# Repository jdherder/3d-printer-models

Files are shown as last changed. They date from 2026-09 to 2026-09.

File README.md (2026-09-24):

# 3D Printer Models

Models for 3D printing on a **Bambu Lab A1**: scans from Polycam (iOS), edits in
Autodesk Fusion, and reproducible Python cleanup pipelines.

## Projects

| Project | Status | Description |
|---|---|---|
| [gate-footing](projects/gate-footing/) | Real size (100 mm), print-ready STEP + STL; next: test print | Plastic foot that holds up a metal gate |

## Layout

- `projects/<name>/` has one folder per model: `source/` (raw), `build.py`,
  `output/` (print-ready), `renders/` (previews), and a `README.md` with status and notes
- `tools/` holds shared mesh tooling (`meshkit.py`, `render.py`, `inspect_mesh.py`)
- `docs/` holds workflow notes for the [A1](docs/bambu-a1.md), [Fusion](docs/fusion.md),
  [Polycam scanning](docs/scanning-polycam.md), and the [model review process](docs/review.md)
- `CLAUDE.md` is guidance for AI agents working in this repo

## Quick start

```bash
pip install -r requirements.txt
python projects/gate-footing/build.py
python tools/inspect_mesh.py projects/gate-footing/output/gate-footing.stl
python tools/make_viewer.py projects/gate-footing   # interactive 3D review page
```

New project: copy `projects/_template/` to `projects/<name>/` and fill in the README.

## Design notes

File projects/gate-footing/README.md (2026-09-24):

# Gate footing

A plastic foot that holds up a metal gate. It's a rectangular base slab with
two raised uprights running front to back, and a slot between them where the gate sits.

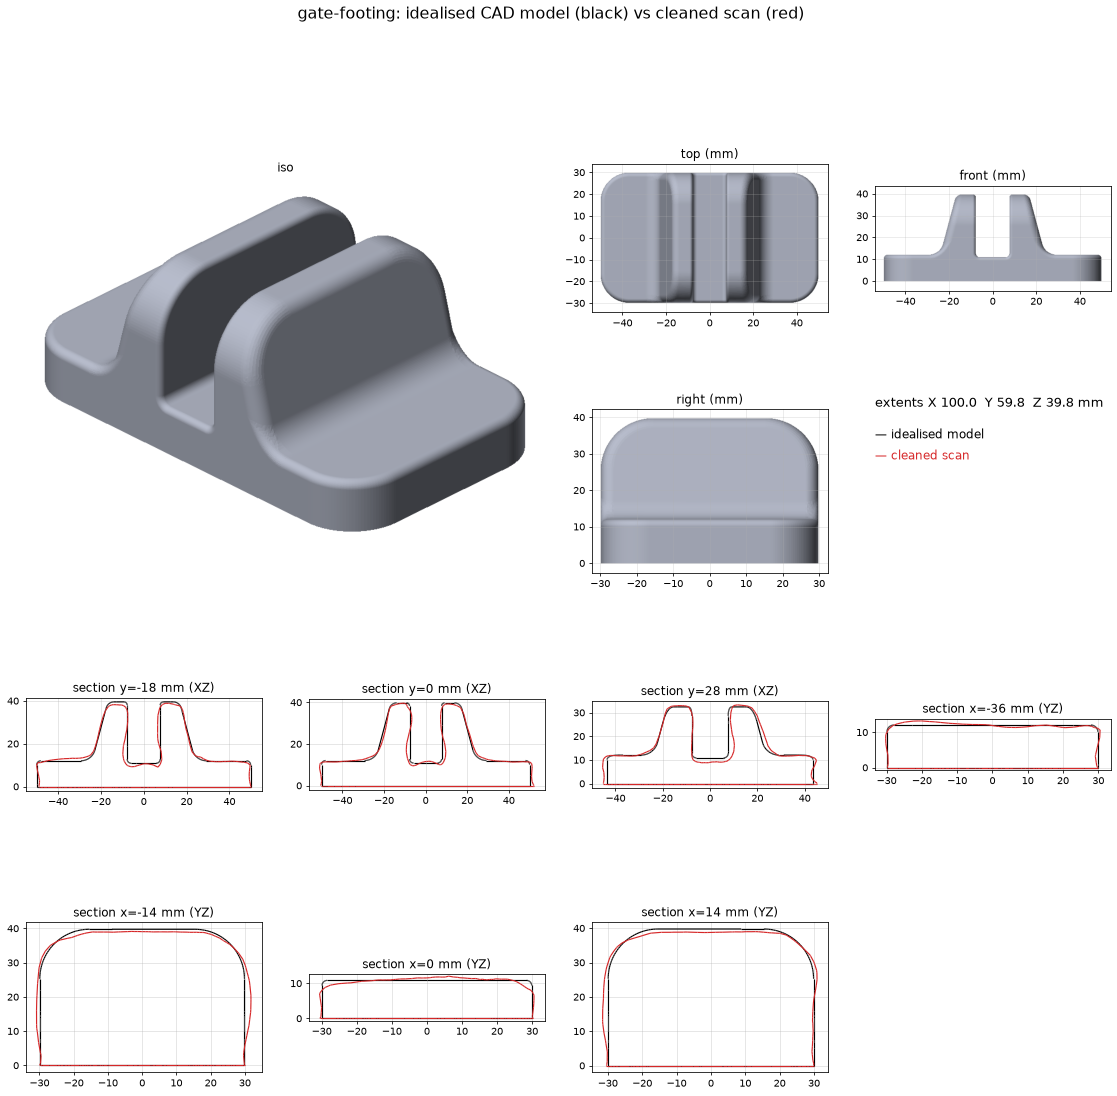
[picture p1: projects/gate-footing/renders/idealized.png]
idealised model vs scan


## Goal

A clean, smooth, accurate, printable model of the footing. The real part has smooth
sides and edges, and the scan is wavy, so the deliverable is an **idealised
parametric CAD model** fitted to the scan, not a smoothed scan.
*(Owner to confirm the end use: print a replacement? exact replica or improved?)*

## Status

- [x] Polycam scan imported (`source/polycam-2026-09-24.glb`)
- [x] Scan cleaned: floor removed, levelled, squared up, flat base, watertight
- [x] **Idealised CAD model** (`idealized.py`, build123d): flat faces, flat parallel
      slot walls, straight drafts, true fillets, mirror-symmetric. Exported as
      STEP (Fusion) and STL (Bambu Studio). Mean deviation from the scan is 0.6 mm at real size
      (2.5 mm at scan scale), mostly where the scan is wavy.
- [x] **Real size:** 100 mm long (the owner's measurement) with the slot modelled at 15.4 mm (caliper 15.1 mm + print clearance). Output is 100 × 59.8 × 39.8 mm and
      fits the A1 in one piece.
- [ ] Check the width (59.8), height (39.8) and base thickness (12.0) against the real part.
      These are scaled from the scan, not measured.
- [ ] Underside: solid, hollow, or ribbed? (not captured)
- [ ] Choose the material and orientation, then test print (scale down first to check the fit?)

## Measurements

**Real (owner, 2026-09-24):** longest dimension **100 mm**. Slot **15.1 mm** (caliper). The first estimate was "right around 15".
Both are set in `build.py` (`MEASURED_LENGTH_X_MM`, `MEASURED_OVERRIDES`). The two agree:
scaling the scan to 100 mm makes the slot 15.9 mm, which confirms the scan's proportions.

`FootingParams` in `idealized.py` holds the values at scan scale. Real = scan × k, where k = 100 / 415 = 0.241.
Only **measured** values were measured directly. Everything else is scaled from the scan.

| Parameter | Scan scale (mm) | Real (mm) | Source |
|---|---|---|---|
| `length`: end wall to end wall (X) | 415 | **100.0** | measured |
| `width`: along the slot (Y) | 248 | 59.8 | scaled |
| `height`: top of the uprights | 165 | 39.8 | scaled |
| `base_h`: base slab thickness | 50 | 12.0 | scaled |
| `slot_w`: gap between the uprights | 66 | **15.4** | measured 15.1 + 0.3 print clearance |
| `slot_floor`: slot floor height | 45 | 10.8 | scaled |
| `upright_outer_x`: outer face at base top, from centre | 100 | 24.1 | scaled |
| `upright_draft_deg`: outer face lean | 15° | 15° | scan |
| `footprint_corner_r` | 55 | 13.3 | scaled |
| `upright_fillet_r` (upright to base) | 28 | 6.7 | scaled |
| `upright_end_r` (top corners at the Y ends) | 60 | 14.5 | scaled |
| `upright_top_outer_r` / `upright_top_inner_r` | 15 / 6 | 3.6 / 1.4 | scaled |
| `base_edge_r` / `slot_floor_r` | 8 / 8 | 1.9 / 1.9 | scaled |

## Modelling decisions (idealised model)

- **The slot walls are flat, parallel, and vertical** (as the owner described). The scan's
  slot interior is its noisiest area (the camera can't see into it), and it read as 60–75 mm
  wide at scan scale depending on height. The model uses the owner's caliper reading of 15.1 mm plus
  0.3 mm clearance, so **15.4 mm**.
- The upright *outer* faces have a 15° draft. That's consistent across the scan
  (x = 92 → 76 mm over z = 80 → 140).
- The part is mirror-symmetric about the slot centre. The scan's slot centre was 2.5 mm off,
  and the cleaned scan is shifted to match.
- The upright top edges are flat and rounded. The scan's top is slightly crowned (≤3 mm),
  which is treated as noise.
- Solid underneath. The real underside is unknown. For printing, use infill or
  hollow it later.

## Printing notes

- 100 × 59.8 × 39.8 mm, so it easily fits the A1 in one piece. Print it **base down with no supports**:
  the drafts, fillets and rounded upright ends are all self-supporting.
- Solid volume is 110 cm³. With 4–5 walls and 20–30 % gyroid infill, expect roughly 50–70 g.
- Outdoors under load: **PETG**.
- The slot is modelled at 15.4 mm so that it prints at about the real 15.1 mm (printed slots usually come out
  ~0.2–0.3 mm narrow). If the test print is too tight or too loose, adjust `slot_w` in `MEASURED_OVERRIDES`
  and rebuild.

## Pipeline

`python projects/gate-footing/build.py` (about 1.5 min):
1. **Scan cleanup** (`tools/meshkit.py`): merge seam vertices → RANSAC ground plane,
   level to Z=0 (mm, Z-up) → keep the largest piece above 2 mm → crop to a 400 mm radius →
   square the footprint → drop the cut edge to Z=0 and cap → watertight.
2. **Idealised model** (`idealized.py`, build123d/OpenCASCADE): base box → drafted
   upright block → slot cut → fillets. The model is **always built at scan scale**, with
   measured overrides converted to that scale, and then the finished solid is scaled by k.
   At 100 mm the small fillets tessellated into self-intersections, and a uniform scale of the
   finished solid is exact. Exported as STEP. Tessellated and repaired to STL
   (`meshkit.cad_to_mesh`).
3. Scale the scan by the same k, write `report.json` (checks and scan-to-model
   deviation), and render the PNGs.

## Files

- **Interactive viewer:** https://claude.ai/artifact/99u6vaQgsGqaAUmchUXR9R
  (private to the owner). Built from `renders/viewer.html` by `tools/make_viewer.py` using
  `review.json`. Republish to this URL on every review (see `docs/review.md`).
- `source/polycam-2026-09-24.glb`: raw Polycam export (≈2 m of ground around the part)
- `output/gate-footing.step`: **idealised model for Fusion** (editable solid)
- `output/gate-footing.stl`: idealised model for Bambu Studio
- `output/gate-footing-scan-clean.stl`: cleaned but wavy scan, useful as a reference body in Fusion
- `output/report.json`: dimensions, watertight/self-intersection checks, deviation, params
- `renders/idealized.png`: model vs scan, views and cross-sections
- `renders/scan-clean.png`, `renders/raw-scan-context.png`

## Log

- **2026-09-24:** Repo set up. Scan cleaned into a watertight solid. The owner flagged that the size
  is wrong: the scan has no floor left, so the photo-mode scan scale is at fault. Waiting on
  measurements. The owner asked for smooth sides and flat faces, so I built the idealised
  parametric CAD model (build123d), which is symmetric with flat slot walls and real fillets, exported
  as STEP and STL. Watertight, 0 self-intersections.
- **2026-09-24:** First review with the interactive 3D viewer (link above). The owner was happy with
  the idealised shape. The review process is now documented (`docs/review.md`, `/model-review`).
  Next: real measurements for scale.
- **2026-09-24:** Owner measured a 100 mm length and a ~15 mm slot. These agree with the scan's
  proportions (15.9 mm predicted). I rebuilt at real size: 100 × 59.8 × 39.8 mm, watertight, 0
  self-intersections, 0.6 mm mean deviation from the scan, fits the A1. Fixed two scale problems: the base-edge
  selection threshold is now relative to the model's size, and the CAD is built at reference scale and then
  scaled (building directly at 100 mm gave 54 self-intersecting triangles). The viewer now frames the
  part rather than the whole build volume. Next: the owner checks the remaining dimensions, then a test print.
- **2026-09-24:** Owner's caliper reads the slot at ~15.1 mm, and they asked to widen it. Set `slot_w` to 15.4
  (15.1 + 0.3 mm print clearance). Rebuilt: watertight, 0 self-intersections, slot 15.4 mm at every height.
  Next: test print and check the gate fit.

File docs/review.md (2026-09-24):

# Model review process

Use this to review a model with the owner after any meaningful change (first
cleanup, idealised rebuild, new measurements, a fix after a test print). It
pairs the agent's automated checks with an **interactive 3D page** the owner
can spin around on any device.

In a Claude session, run **`/model-review <project>`** (skill:
`.claude/skills/model-review/`). It runs every step below.

## 1. Rebuild from source

```bash
python projects/<name>/build.py
```

Outputs are always regenerated, never hand-edited. The build must finish
without assertion failures.

## 2. Automated checks (agent)

Read `projects/<name>/output/report.json` and confirm:

| Check | Pass |
|---|---|
| `watertight`, `winding_consistent` | `true` |
| `self_intersecting_faces` | `0` |
| `euler_number` | `2` for a single solid with no through-holes (each through-hole subtracts 2) |
| `scale_status` | Measured. If it's still scan scale, **say so plainly**, because the size is not real |
| `fits_A1_as_is` / `fits_A1_any_axis_order` | If false, the part needs splitting or scaling |
| `scan_to_model_deviation_mm` (idealised models) | Mean within a few mm. Look at *where* the large deviations are |

For any other mesh: `python tools/inspect_mesh.py <file>`.

## 3. Visual check (agent)

Read the PNGs in `projects/<name>/renders/` (the agent can't open a 3D viewer,
but it can look at images):
- Shaded views: does the shape look right, and are there artefacts (spikes, holes, a leftover floor)?
- Cross-sections, model (black) vs scan (red): the model should sit on the scan's
  average surface. A consistent offset in one place is a modelling error, not
  scan noise.

Fix anything found before involving the owner.

## 4. Interactive review page

```bash
python tools/make_viewer.py projects/<name>
```

This reads `projects/<name>/review.json` and writes `renders/viewer.html`, a
single self-contained page (~0.5–1 MB) with:
- orbit, zoom, and pan, plus Iso/Front/Side/Top buttons
- a toggle for each mesh (e.g. the idealised model as a solid, the original scan as a wireframe overlay)
- the Bambu A1 256 mm build volume for size context
- a **"preview at real size"** box: type a length and every dimension plus the A1
  fit check updates
- a notes panel (what changed, what to look at)

`review.json` fields are documented at the top of `tools/make_viewer.py`.
Dimensions can point at model parameters (`"param": "slot_w"`), so the page always
matches the last build. Meshes must be under 65k vertices.

**Share it:** in a Claude session, publish `renders/viewer.html` as an Artifact.
Record the artifact URL in the project README (under *Files*). Next time,
publish to that same URL so the owner's link keeps working. Without Claude, open
`viewer.html` in a browser (it needs internet access for three.js).

## 5. Owner review checklist

Ask the owner to look for:
1. **Shape:** does it match the real part? Anything missing, like holes, ribs, or text?
2. **Flat faces and edges:** are faces flat where they should be, and are the edge
   roundings about the right size?
3. **Scan overlay:** toggle the scan on. Where the model and scan disagree, which is right?
4. **Size:** type the measured length into the real-size box. Do the listed
   dimensions (slot width etc.) match their tape measure?
5. **Fit and printing:** does it fit the A1? Any orientation or material concerns?

## 6. Record the outcome

In the project README:
- tick or add items under **Status**
- put new real measurements in **Measurements**, and in `build.py`
  (`MEASURED_LENGTH_X_MM` / `MEASURED_OVERRIDES`)
- add a dated **Log** entry: what was reviewed, the owner's feedback, and what changes next

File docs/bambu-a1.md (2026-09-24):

# Bambu Lab A1 notes

- **Build volume:** 256 × 256 × 256 mm. Parts bigger than that get split, with
  alignment pins or dovetails, or scaled down.
- **Kinematics:** bed-slinger (the Y axis moves the bed). Tall, narrow parts wobble,
  so orient long axes along X where possible, or add a brim.
- **Enclosure:** none. ASA and ABS warp and crack, so avoid them. PLA and PETG are
  the everyday materials, and TPU works for flexible parts.
- **Nozzle:** 0.4 mm stock (hardened 0.4 / 0.2 / 0.6 / 0.8 swaps available).
- **AMS lite:** multi-colour is possible, but assume single material unless told otherwise.
- **Slicer:** Bambu Studio. STL is fine. 3MF keeps plate and settings. STEP imports
  as solids.

## Material guidance

| Use | Material | Notes |
|---|---|---|
| Indoor, decorative, jigs | PLA | Easiest. Softens around 55 °C and creeps under constant load |
| Outdoor, sun, load-bearing | **PETG** | UV/heat tolerant enough, tougher. Dry the filament first |
| Flexible feet, bumpers | TPU 95A | Print slowly, no AMS |

## Design rules of thumb (0.4 mm nozzle)

- Walls: at least 1.2 mm (3 perimeters). Structural parts: 4–6 perimeters plus 15–30 % gyroid infill.
- Overhangs up to ~45° without supports. Bridges up to ~30 mm are fine.
- Clearance for press or slip fits between printed parts: 0.2–0.3 mm per side.
- Holes print slightly undersize, so add ~0.2 mm, or drill or ream them.
- Put the flat, largest face on the bed. Lay out layer lines so loads don't split
  them apart (layers are weakest in Z).

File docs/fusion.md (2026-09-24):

# Autodesk Fusion workflow

## Opening an idealised model (preferred)

When a project has `output/<name>.step`, use **File → Open** (or Insert → Insert
into Current Design). It arrives as a real solid body with fillets, ready to edit
with Press Pull, Fillet, and so on. The parameters live in the project's `idealized.py`.
Tell the agent about any changes so it can mirror them (or export your edited
STEP into `fusion/`).

## Bringing a cleaned scan into Fusion

1. **Insert → Insert Mesh** and pick `projects/<name>/output/*-clean.stl`.
   Set the units to **millimetres**. The mesh is already Z-up with its base on Z=0.
   (Fusion's default is Y-up. If the model lies on its side, go to Preferences →
   General → Default modeling orientation → **Z up**, or rotate it on insert.)
2. Use it as a **reference body**. The best results usually come from sketching
   on top of the mesh:
   - Mesh workspace → **Create Mesh Section Sketch** at a few heights and planes.
   - Trace the profiles with lines, arcs, and fillets, then extrude or revolve
     a clean solid.
3. Or convert it directly (only good for simple, low-poly meshes):
   Mesh → **Modify → Convert Mesh** (Prismatic or Faceted). Big scans convert
   slowly and give a faceted body that's awkward to edit.

## Handing work back to the repo

Put Fusion outputs in `projects/<name>/fusion/`:
- `*.step`: the solid, for re-import or the slicer (Bambu Studio opens STEP)
- `*.stl` or `*.3mf`: the mesh for printing
- A note in the project README with the key parameters (user parameters in
  Fusion, like slot width and wall thickness), so agents can reason about them.

Export tips: File → Export → STEP. For printing, right-click the body →
**Save As Mesh**, choose 3MF or STL, and set the refinement to High.

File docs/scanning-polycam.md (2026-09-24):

# Scanning with Polycam (iOS)

## Export

- Export **GLB** (textured mesh, metres, Y-up) and drop it in
  `projects/<name>/source/` with a dated name, for example `polycam-2026-09-24.glb`.
- `tools/meshkit.load_scan` handles GLB, OBJ, PLY, and STL.

## Scale is not reliable

Photo mode builds geometry from photos. Its absolute size can be far off. The
gate-footing scan came out obviously too big. LiDAR mode (Pro iPhones) is closer
but still not caliper-accurate. **Always record at least one real measurement**
(overall length is easiest) in the project README. `build.py` scales the mesh to
match it.

Better: put an object of known size in the scene (a ruler or a credit card,
85.6 × 54 mm) so the scale can be checked afterwards.

## Getting better scans

- Put the object on a plain surface with some texture (not glossy, not
  featureless). Dark or shiny plastic scans poorly, and a light dusting of
  talc or dry shampoo helps.
- Walk a full orbit at two or three heights, with lots of overlap. Get down low
  for vertical faces.
- Slots, holes, and undersides won't be captured if the camera can't see them.
  Scan the object upside-down separately if the underside matters, or measure
  those features by hand.
- Crop tightly in Polycam if you can. The pipeline removes the floor anyway,
  since it fits the ground plane and cuts just above it.

## What the pipeline does (`tools/meshkit.py`)

1. Merges the texture-seam duplicate vertices.
2. Fits the ground plane with RANSAC, then levels it so the ground is Z=0 (mm, Z-up).
3. Cuts 2 mm above the ground and keeps the largest piece (the object).
4. Squares the footprint to X/Y and centres the part.
5. Drops the cut edge to Z=0 and caps it, giving a flat, watertight base.
6. Reports dimensions, watertightness, self-intersections, and A1 fit.

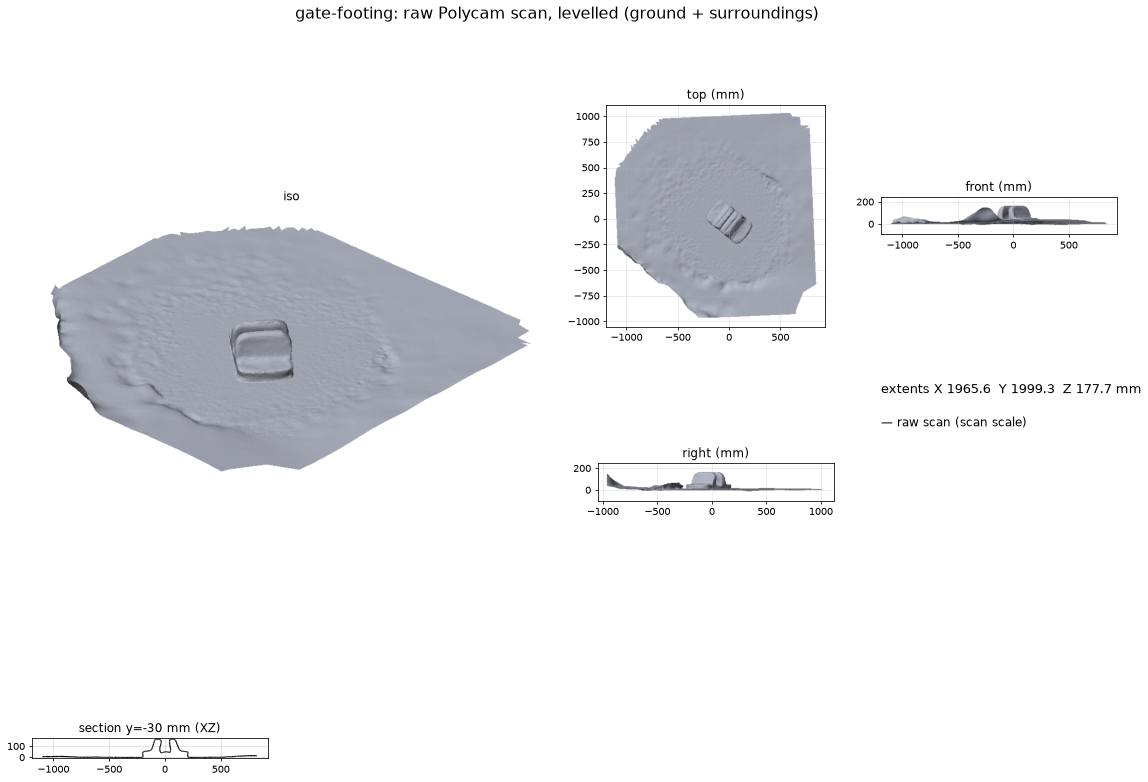
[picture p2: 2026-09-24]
projects/gate-footing/renders/raw-scan-context.png

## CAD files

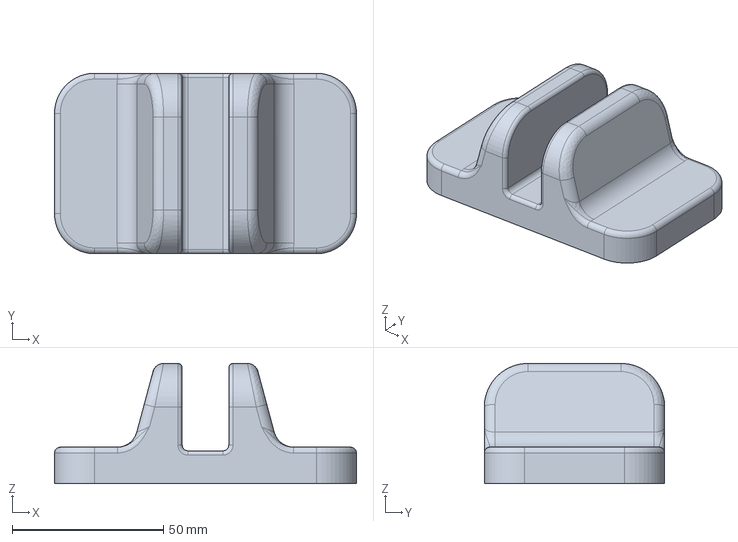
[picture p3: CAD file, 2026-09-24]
projects/gate-footing/output/gate-footing.step
100.0 x 59.8 x 39.8 mm

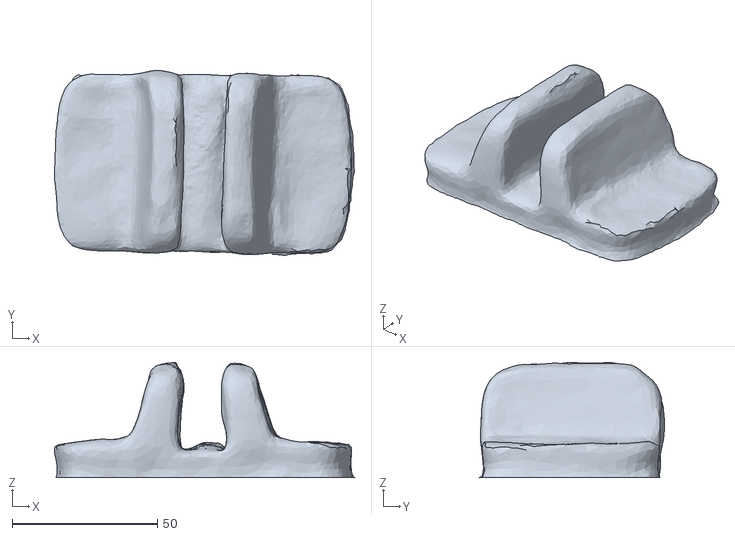
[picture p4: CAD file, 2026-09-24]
projects/gate-footing/output/gate-footing-scan-clean.stl
103.4 x 63.8 x 39.8

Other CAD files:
projects/gate-footing/output/gate-footing.stl

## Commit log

2026-09-24 Set up 3D printing model repo and gate-footing project
    - CLAUDE.md agent guide (A1 printer, Fusion, Polycam, conventions,
    per-project workflow) plus docs/ for printer, Fusion and scanning
    - tools/: meshkit (scan -> watertight solid pipeline, CAD tessellation
    repair, printability report), headless renderer, inspect CLI
    - projects/_template for new models
    - gate-footing: cleaned Polycam scan plus an idealised parametric CAD
    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
    [gate-footing-scan-clean.stl, gate-footing.step, gate-footing.stl]
2026-09-24 gate-footing: rebuild at real size (100 mm long, 15 mm slot)
    - build.py: owner measurements; CAD is built at reference scale with
    overrides converted, then the finished solid is scaled (building
    directly at 100 mm tessellated into self-intersections)
    - idealized.py: base-edge fillet selection is now scale-relative
    - Outputs: 100 x 59.8 x 39.8 mm, watertight, 0 self-intersections,
    0.6 mm mean deviation from scan, fits the A1
    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
    [gate-footing-scan-clean.stl, gate-footing.step, gate-footing.stl]
2026-09-24 gate-footing: widen slot to 15.4 mm
    Owner's caliper reads the real slot at ~15.1 mm; model it at 15.4 mm
    (+0.3 mm) because printed slots come out narrow. Rebuilt outputs are
    watertight with 0 self-intersections; viewer, notes and log updated.
    Claude-Session: https://claude.ai/code/session_01EYn8nTiHyXteLvBCdPkUdN
    [gate-footing.step, gate-footing.stl]
2026-11-01 wagon-cup-holder: clip-on Yeti 20 oz holder for the MAC wagon push bar
    Parametric build123d model: snap C-clip with M4 clamp bolt, floor plate and
    tapered pocket. Bar measured at 22.3 mm; tumbler dims are retailer figures.
    Includes STEP/STL, a 15 mm clip fit-test slice, renders and review viewer.
    Claude-Session: https://claude.ai/code/session_01LioJkD1QCCMNjEhF7jkXVA
2026-11-01 wagon-cup-holder v2: hang the cup off the right-hand side rail
    Owner wanted the cup hanging off the side of the wagon. Photos show the push
    frame is a U-shaped tube with side rails, so the clip now goes on the right
    side rail with a shelf + web carrying the pocket 67.8 mm outboard, base 60 mm
    below the rail. The constant cup twist makes the M4 clamp bolt essential, so
    the head is reached through a hex-key window in the web and the nut slides in
    from the ear's bottom. Adds the owner's six rail photos to source/.
    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
2026-11-01 wagon-cup-holder v3: split into a stay-on clip and a lift-off cup module
    The cup has to come off quickly for folding the wagon. The clip (ring, ears,
    M4 clamp bolt, boss + 45-degree dovetail tongue) is tightened once and stays
    on the rail. The cup module (dovetail block, web, floor, pocket) drops onto the
    tongue from above, rests on the ear tops, and lifts straight off with no tool.
    Drops the shelf and hex-key window. Adds a dovetail fit-test pair and a
    per-piece export. All piece pairs are interference-free in the assembled pose.
    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
2026-11-01 wagon-cup-holder: record owner feedback (strut + latch are outboard; rail is 22.3 mm; retail tumbler dims OK)
    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
2026-11-01 wagon-cup-holder v3.1: move the cup out to clear the end latch + strut
    Owner: latch and diagonal strut are the same at both ends, reach ~26 mm past the
    bar, and the 120 mm is the clear stretch between them; retailer tumbler dims are
    fine for now. web_gap 24 -> 40 mm (cup axis 83.8 mm out, ~0.82 N*m twist), clip
    centred on the module in the window, dovetail block now stands on the bed (fixes a
    flat bridge), approximate latch/strut keep-out zones added and checked.
    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
2026-11-01 wagon-cup-holder v4: replace the slab block with a shaped, flowing bracket
    Owner didn't like the big bulk block between the clip and the cup holder. The new
    neck keeps a constant 4 mm cheek around the dovetail groove and flares at 45 deg
    into the web, with a 16 mm inside fillet under it and an 8 mm blend on top. No
    longer full width; still 0 overhang and 0 interference (clip, rail, tumbler,
    latch/strut zones). Module 190 cm3 (was 203).
    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
2026-11-02 wagon-cup-holder v5: printed M8 knob bolt + hex nut for the clamp
    Owner wants to print the bolt and nut. A printed M4 would strip, so the clip's ears
    are redesigned for a printed M8 x 1.5 bolt with a scalloped hand knob and a 13 mm hex
    nut (fasteners.py generates the threads as a mesh). Ears 8 -> 10 mm, 9 mm bolt hole,
    nut pocket + slide-in slot on both ears, clamp test slice 15 -> 26 mm. Bolt/nut are
    watertight, mesh at any position with 0 interference, and clear the clip, module and rail.
    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
2026-11-02 wagon-cup-holder v5.1: clean up the notch in the holder piece
    The back wall was a full-height plate sticking ~19 mm past the lip of the curved wall,
    with a hard corner and a thin slit between them. Now the web stops at z_top (set by
    the dovetail groove's cheek), its top corner is chamfered along the pocket circle up to
    the lip, the opening angle is derived so the lip ends level (wrap 250 -> 262 deg), and
    the whole module is cut flat at that height. Module 88 -> 73 mm tall, 188 -> 184 cm3.
    Still 0 overhang and 0 interference.
    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
2026-11-02 wagon-cup-holder v6: rebuild both pieces as one blended, flowing form
    Owner still saw weird notches, walls and angles. Every earlier version was flat prisms
    with fillets. Now the module (a tapered closed cup ring printed upright, with a slim stem
    sweeping to the dovetail pad) and the clip are each one signed-distance field with smooth
    blends, meshed with marching cubes; the dovetail, rail bore, mouth, bolt hole and nut pockets
    are cut exactly afterwards. No side opening, flat top plane with rounded edges, 45-degree
    base chamfer, no supports. Pieces are now STL meshes (STEP files removed; v5.1 has them).
    Single watertight bodies, 0 interference, module 142 cm3. Adds scikit-image.
    Co-Authored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
2026-11-03 wagon-cup-holder: use a real M8 bolt, nut and fender washer (printed bolt snapped)
    Owner's printed M8 bolt snapped and didn't fit the printed nut. The clip's holes and pockets
    already take standard hardware: M8 x 45 hex bolt, M8 hex nut (13 AF, not nyloc), M8 fender
    washer ~24 mm OD; or 5/16-18 x 1-3/4. Lengths checked against the model. README updated.
    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
2026-11-03 wagon-cup-holder v6.1: clip sized for ordinary M4 hardware (M4 x 30 works)
    Printed M8 bolt snapped; M8 then needed 45 mm bolts and most kits stop short of 40 mm even in M4.
    Ears 10 -> 8 mm, 4.5 mm bolt hole, screw head + 9 mm washer in a 5 mm round pocket in the inboard
    ear, nut in a 5 mm hex pocket in the outboard ear (3 mm walls behind both), so M4 x 30 engages 2.5 of
    the nut's 3.2 mm and M4 x 35 fully. Clamp slice 26 -> 20 mm. Screw, washer and nut modelled as ghosts
    for fit checks (12 interference checks pass). Module unchanged in function: the printed one still
    fits. Removes fasteners.py and the printed bolt/nut STLs.
    Claude-Ses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
2026-11-03 wagon-cup-holder: record the M4 hardware kit the owner chose (Kernmax 320 pcs)
    M4 x 30 and x 35 are included; head, nut and washer sizes match the clip's pockets.
    Notes: check the flat washer is ~9 mm OD, black oxide rusts outdoors, tighten gently.
    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
2026-11-03 wagon-cup-holder: strut measured (13.5 mm square); add a strut-grip test piece
    Owner folded the handle: the bolted clip left on the bar blocks the fold. Idea: a clip that
    also grips the angled strut (two points locate it, no screw, pops off in one motion), keeping the
    dovetail. Strut is 13.5 mm square; photo-derived estimates: faces ~7/20 mm past the bar surface,
    slope ~55 deg. Adds wagon-strut-grip-test.stl (three C-clips, 0.2/0.4/0.6 mm clearance), the two
    measurement photos, and README notes.
    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
2026-11-03 wagon-cup-holder: record strut depth/slope from the owner's tape photos; add the photos
    Three vertical-tape photos give the strut's depth below the bar at three places: a straight line
    at ~59 deg, depth ~ 1.63*x - 7 mm from the strut's pivot screw. Shallow at the strut-side end of
    the clear stretch, so the two-point clip's ring should sit at that end with a short (~30 mm) leg.
    Bar-to-strut gap from two top-down photos disagrees (4 vs 7 mm); asked for a ruler reading.
    Six source photos added, README updated. Two-point clip not yet modelled.
    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
2026-11-03 wagon-cup-holder v7: two-point pop-off clip (ring on rail + C-grip on angled strut), no hardware
    Replaces the M4 screw clamp, which left a clip on the bar that blocked folding the handle.
    Adds the strut model, strut-grip test pieces, interference and gap-sensitivity checks, and
    updates the review viewer and README. The clip needs supports under the grip and leg.
    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
2026-11-03 wagon-cup-holder v7.1: stronger strut grip (deeper lips, thicker walls, tighter fit, longer grip)
    The v7 clip fit well but the strut grip un-snapped under a full cup. Lips 1.0 -> 1.6 mm, walls 2.5 -> 3.0,
    clearance 0.4 -> 0.3, grip 18 -> 22 mm. New grip test with three lip depths.
    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
2026-11-03 wagon-cup-holder v8: flip the strut grip so a full cup presses it on
    The C's closed wall now faces the cup and its mouth faces the bar, so the cup's load pushes the strut into
    a solid wall instead of out through the mouth. The inboard leg is replaced by a diagonal arm to the grip's
    up-slope side. New grip test (lips 1.2/1.6/2.0 mm).
    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
2026-11-04 wagon-cup-holder v8.1: vent hole in the pocket floor so the tumbler doesn't suck the module off the dovetail
    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
2026-11-04 wagon-cup-holder v8.2: open up the cup pocket so the tumbler can't wedge
    Floor clearance 2 -> 4 mm on the diameter plus 0.02 mm/mm draft toward the rim.
    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
2026-11-04 wagon-cup-holder v8.3: tighter dovetail (0.35 -> 0.20 mm per side), three groove test blocks
    Only the module changes; the clip is byte-identical.
    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
2026-11-05 wagon-cup-holder v9: mirrored left-hand clip (shared cup module)
    Adds output/wagon-cup-clip-left.stl, the mirror image of the right clip, with its own interference checks
    against the mirrored strut and latch zones. The module is symmetric along the rail, so it fits both sides.
    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
2026-11-05 wagon-cup-holder v9.1: ring in the middle of the clear stretch, strut grip ~73 mm down on a long post, more slack
    Both clips change (the module doesn't). Grip: 1.5 mm slack on the cup side, 0.4 mm clearance, 1.2 mm lips.
    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
2026-11-06 pegboard-hook v1: parametric wire hook traced from the owner's photos
    Claude-Session: https://claude.ai/code/session_01LioJkDjorNwvwRbmSgpVGL
2026-11-06 pegboard: shared peg interface (tools/pegboard.py) + fit-test piece
    The steel hook becomes the baseline for custom pegboard parts: board frame,
    board specs, hook and pin pegs (sized from the hook), board mesh and
    interference check, print pose. Docs in docs/pegboard.md.
    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
2026-11-06 pegboard: owner's board (Menards 3/16 white hardboard) is the default; hook jog fitted to it
    Board from retailer listings: 9/32 in holes, 0.155 in thick. Fit checks
    now leave 0.2 mm per side (FIT_CLEARANCE). The traced hook's S-jog could
    not hang flush on a 1 in grid; it is now defined by the hole it passes
    through (12 deg) and clears.
    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
2026-11-06 pegboard: owner-measured 1/4 in holes, pegs 5.9 mm after loose test prints, plate rocks in
    - DEFAULT_BOARD holes 7.14 -> 6.35 mm (owner measured ~0.25 in, 1 in centres)
    - PegStyle.d 5.53 -> 5.9; the printed hook uses it too
    - mount_plate stops just above the hooks and rounds its top back edge
    - hook S-jog levelled (any slope binds in 6.35 mm holes with a 5.9 mm wire)
    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
2026-11-06 pegboard: hook back to the 12 deg jog, pegs 6.1 mm, peg gauge 6.0-6.4 mm
    The owner's v5 print (level jog) was much harder to get in than v4 (12 deg),
    and 5.9 mm was still loose. The flush-hang check is now informational for
    the hook. bend_r 3.5 (with a guard) so the thicker wire doesn't
    self-intersect. FIT_CLEARANCE 0.2 -> 0.1.
    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
2026-11-06 pegboard: drop the peg gauge STEP; mark generated outputs in .gitattributes
    The gauge's engraved labels made its STEP ~24k lines, and it's a one-off
    test piece (STL only now). STEP, STL and viewer pages are marked
    linguist-generated so GitHub collapses them in diffs.
    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
2026-11-08 pegboard-spool-holder v1: arm for the A1's active spool, one-column hook + pin
    Claude-Session: https://claude.ai/code/session_01LioJkAEXeUQYr8BtfNU5CY
2026-11-08 pegboard-spool-holder v2: two hooks side by side + two pins, arm spans both columns
    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
2026-11-08 pegboard-spool-holder v3: 3 in hook-to-pin span, second pin row (2 hooks + 4 pins)
    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
2026-11-09 santa-bat-ornament v1: flat hanging ornament traced from the wall-bat photo
    Bat silhouette thresholded from the photo, Santa hat hand-traced, perspective
    squash corrected (1.23x, est.), scaled to 100 mm, 3 mm thick with a 3.2 mm
    hanging hole through an enlarged pom-pom. Single-colour STL plus a 3-part
    3MF (bat/hat/trim) for the AMS lite, SVG outline, renders and viewer.
    Claude-Session: https://claude.ai/code/session_01LioJkBms5W4SF5Vq1r1PX2
2026-11-09 santa-bat-ornament v3: 50 mm, 2.4 mm thick, three colours; pom-pom and loop resized for the small scale
    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
2026-11-09 santa-bat-ornament v5: tiny hanging hole in the black wing instead of the ring (hangs tilted)
    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
2026-11-09 santa-bat-ornament v6: back to a hanging hole through the pom-pom, smallest reliable size (1.2 mm)
    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
2026-11-09 pegboard-bambu-sign v1.1: Bambu Lab logo sign for the pegboard
    250 x 120 mm sign (as wide as the A1 bed allows) with the full Bambu Lab logo
    (mark + text) raised 1.2 mm as a second colour: prints face up with a single
    colour change. Hangs on two small hangers (shared hook + pin + T-stud) via
    hidden keyhole slots; build checks slide-on, push-on, retention and board fit.
    Claude-Session: https://claude.ai/code/session_01LioJkCDvj2h4Xz1a53Mc35
2026-11-09 pegboard-bambu-sign v1.2: sloped 5.7 mm hooks so the hangers rock in; add pb.rock_in check
    New pegboard.rock_in simulates tilting a hung part off the board with 0.3 mm
    of hole give, calibrated on the owner's hook prints (passes v4's 12 deg S-jog,
    fails v5's level step). It shows the level 6.1 mm shared hook jams, so the
    sign's hangers now use a 5.7 mm hook sloped 12 deg (hook_peg slope_deg /
    mount_plate hook_slope_deg, default unchanged). The fit test and spool holder
    also fail the check; flagged in docs/pegboard.md, not changed.
    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
2026-11-09 Pegboard catalog: sloped 5.7 mm hooks + 6.1 mm pins in shared PegStyle; rock-in checked
    PegStyle gains hook_d (5.7) and hook_slope (12 deg); d stays the 6.1 mm pin.
    hook_peg slopes by default and mount_plate follows. The fit test (v4), spool
    holder (v5) and sign hangers now use it, and their builds assert pb.rock_in
    instead of the strict flush overlap (kept as info). The steel-hook copy (v7)
    goes back to its 5.53 mm wire (6.1 and 5.7 both jam on its S-jog) with a
    6.1 mm pin. Docs, READMEs and viewers updated.
    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
2026-11-11 pegboard-mat-holder v0.1: concept slotted strip for the A3 + A4 cutting mats
    Claude-Session: https://claude.ai/code/session_01LioJkDGY2g7bcfC9PCDKps
2026-11-11 pegboard-mat-holder v0.2: slots 3.5 mm for the calipered 2.5-3.0 mm mats
    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
2026-11-11 bike-hook v1: vertical PETG bike hook for a horizontal 2x4
    Lip over the 2x4 carries the weight; two vertical lip screws (shear) and a
    plate-face screw hold it. Prints on its side with no supports so bending runs
    along the layers. Build reports a beam strength estimate, screw access, and
    a 700c wheel/spoke fit check. Viewer published.
    Claude-Session: https://claude.ai/code/session_01LioJk9tSecgRewayDeGKSN
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2026-11-11 bike-hook v3: adult + kids' variants checked against the family's 4 bikes
    Owner photos (saved in source/) show a Trek FX 7.2 and Schwinn Trailway
    (700c), a Nishiki 20 in and a Dynacraft 16 in, and a flat 2x4 with wood
    behind three pegboard hole rows. Spokes are now modelled crossed. The adult
    hook fits both hybrids; a kids' variant (16 x 38 mm bar, seat 140 mm out)
    fits the 16/20 in wheels. Plates get a bottom chamfer for tire clearance.
    Each bike is checked against its hook (rim seating, spoke gaps, loads), and
    the four are laid out 18 in apart for the viewer.
    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
2026-11-11 bike-hook v3.1: nicer plates and holes
    Rounded outline corners (45 deg cut on the corner that prints on the bed),
    5 mm chamfer on the front edges, flush 13.6 x 3 mm counterbores, truncated
    teardrop holes instead of pointed ones, and ADULT/KIDS labels pressed into
    the face. Adds renders/plates.png. Also fixes the README's left/right:
    facing the wall, the bar points left.
    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
2026-11-11 pegboard-bambu-sign v2: one-piece badge printed face-down, no supports
    Redesign after the v1.2 test print (the hanger slots needed supports, and one
    end of the top surface came out rough). The logo is now on one line, cut to
    its outline, with the dark badge, white letters and green mark inlaid flush
    0.8 mm. It prints face-down: the front is the first layers on the plate, all
    colour changes are in those layers, and the pegs stand straight up.
    tools/pegboard.py: PegStyle.hook_leg_angle (default 90, unchanged) lets the
    hook's behind-board leg rise at 45 deg so it prints upright without support.
    The badge uses it with hook_gap 4.8 / hook_rise 6 and passes pb.rock_in.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
